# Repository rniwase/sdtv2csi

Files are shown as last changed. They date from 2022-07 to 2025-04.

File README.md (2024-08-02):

# sdtv2csi - SDTV to MIPI CSI-2 Video Decoder
Board for converting SDTV analog video to MIPI CSI-2 using Analog Devices ADV7280A-M.

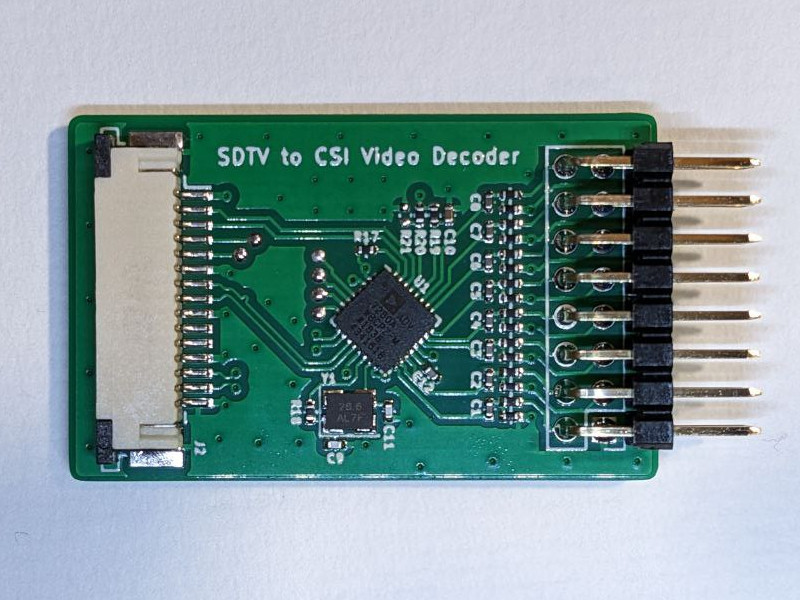
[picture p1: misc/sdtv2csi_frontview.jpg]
sdtv2csi topview

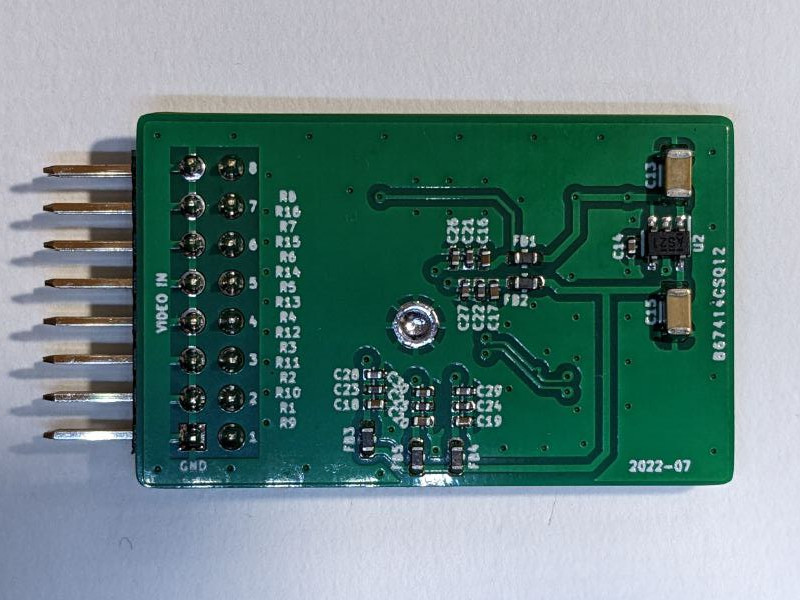
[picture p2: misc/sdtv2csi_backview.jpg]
sdtv2csi backview


## Configuration example in Raspberry Pi 4
1. Get and run kernel patch installation scripts
```
wget https://github.com/rniwase/sdtv2csi/raw/master/rpi/install_patch.sh
sudo bash install_patch.sh
```

2. Set dtoverlay in config.txt
```
# for Raspberry Pi OS Bookworm:
sudo bash -c 'echo "dtoverlay=adv728x-m,adv7280m=1" >> /boot/firmware/config.txt'
# for Raspberry Pi OS Bullseye:
sudo bash -c 'echo "dtoverlay=adv728x-m,adv7280m=1" >> /boot/config.txt'
```

3. Reboot the system and check for devices.
```
sudo reboot
sudo v4l2-ctl --all -d /dev/video0
```

### Operation check by FFmpeg
1. Connect NTSC composite video signal to VIDEO_IN pin header AIN1-GND

2. Install FFmpeg
```
sudo apt update
sudo apt install ffmpeg
```

3. Video recording
```
# Record full video including blanking line
ffmpeg -an -video_size 720x507 -r 29.97 -i /dev/video0 -c:v rawvideo -vf realtime -t 5 out.asf
# Record video with blanking lines cropped
ffmpeg -an -video_size 720x507 -r 29.97 -i /dev/video0 -c:v rawvideo -vf realtime,crop=720:480:0:27 -t 5 out_crop.asf
```

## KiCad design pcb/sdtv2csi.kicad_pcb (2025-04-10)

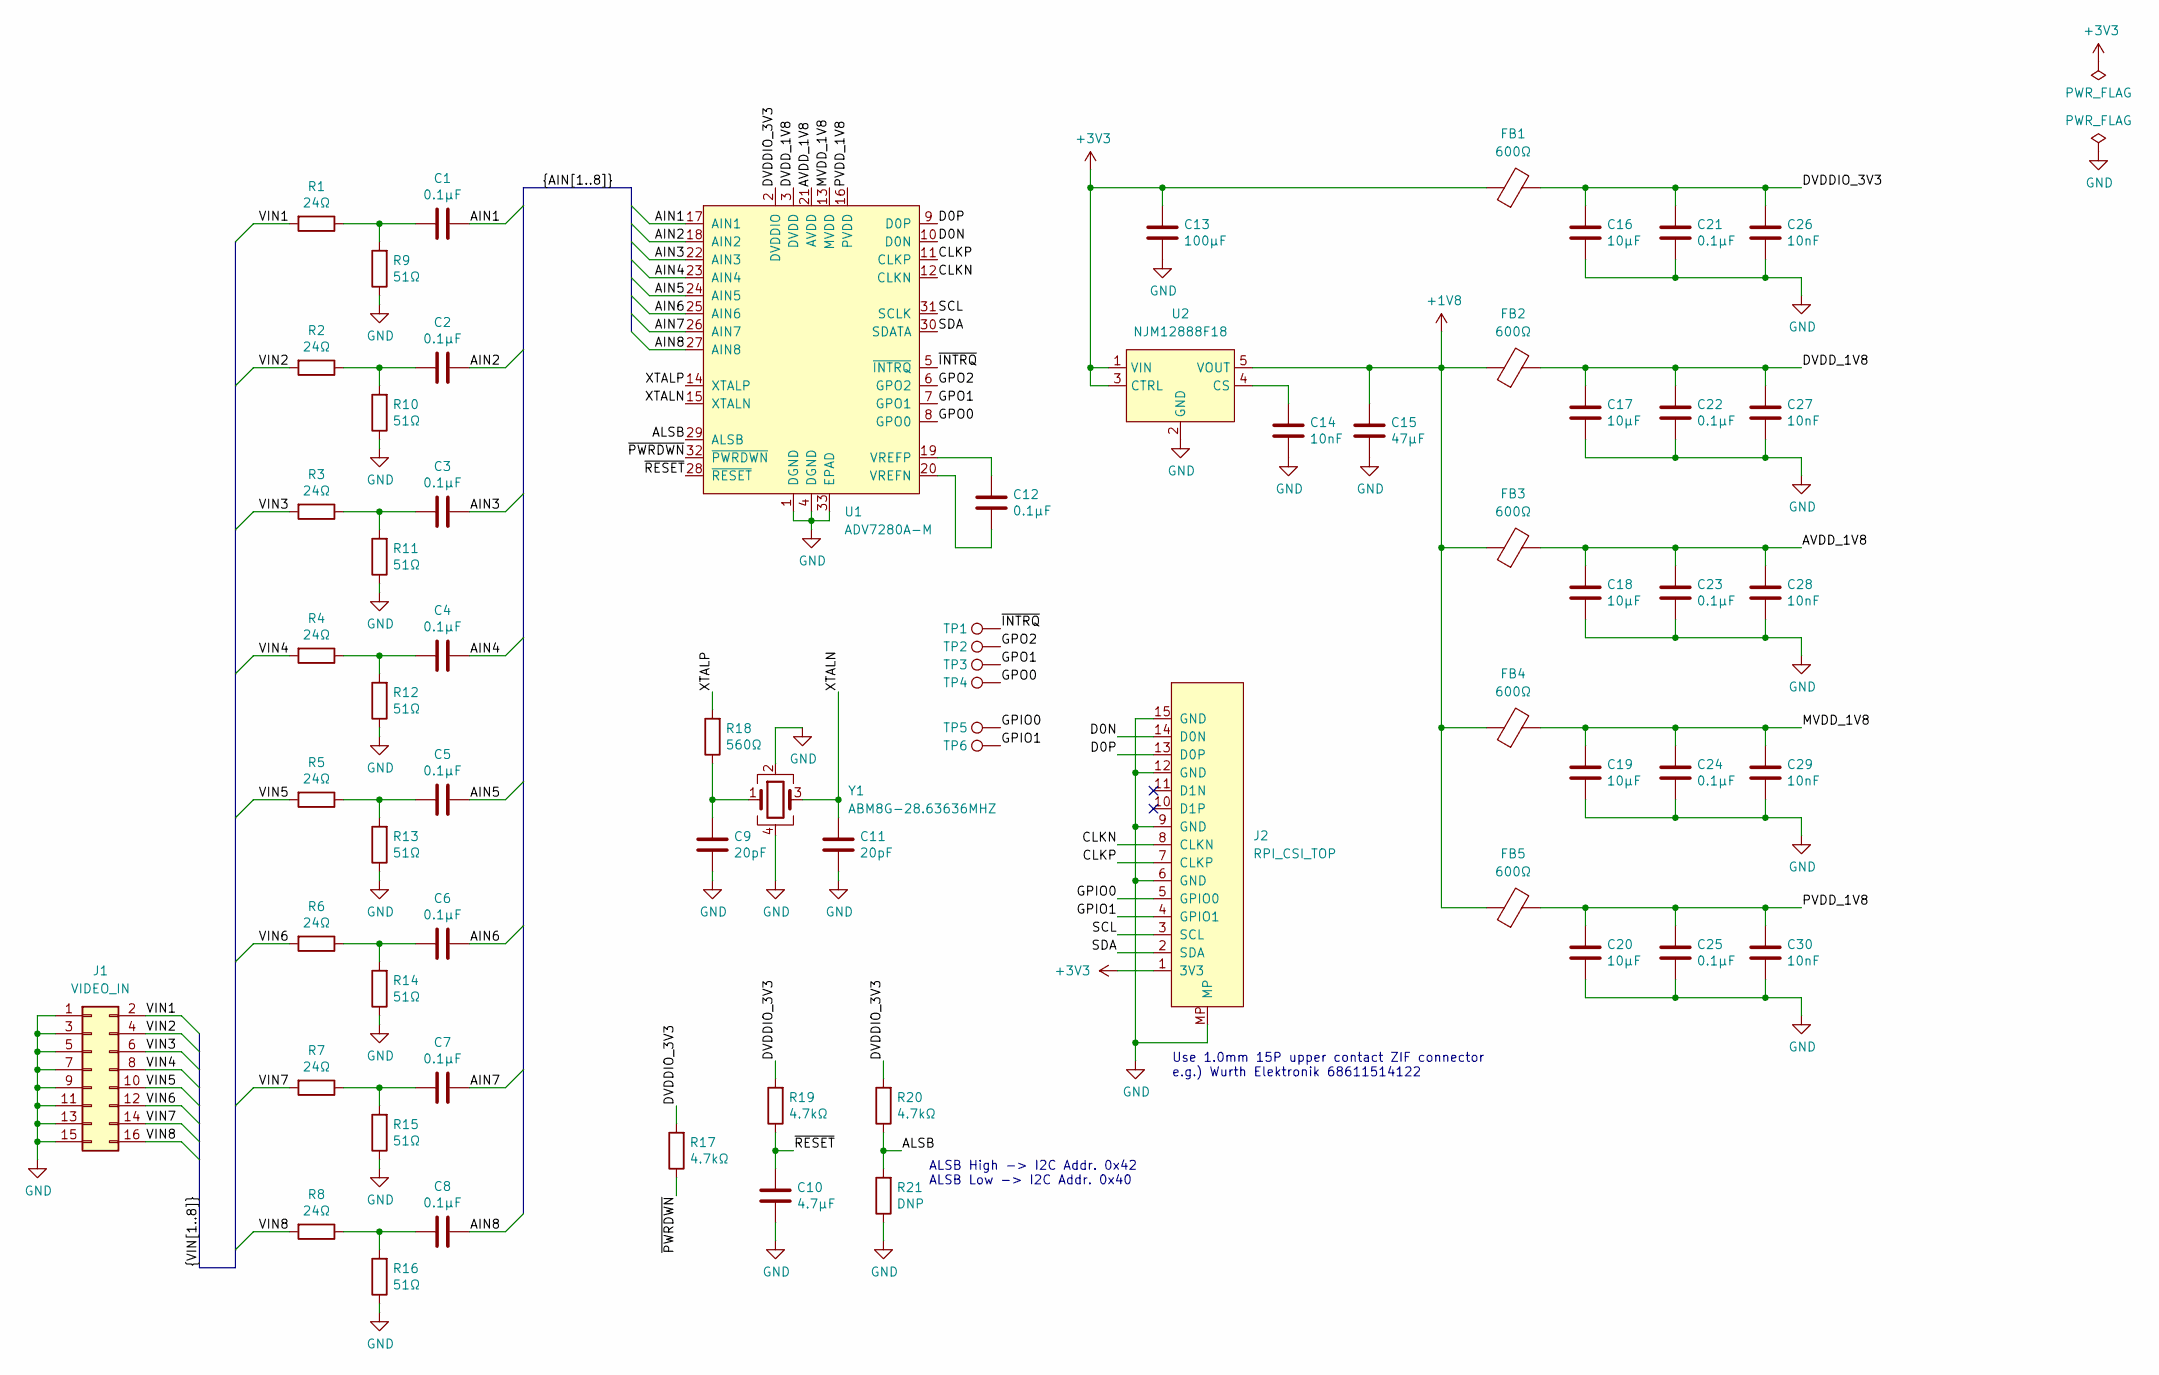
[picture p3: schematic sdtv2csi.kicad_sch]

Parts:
C1, C2, C3, C4, C5, C6, C7, C8, C12, C21, C22, C23, C24, C25: 0.1μF; C_0402_1005Metric
C9, C11: 20pF; C_0402_1005Metric
C10: 4.7μF; C_0402_1005Metric
C13: 100μF; C_1206_3216Metric
C14, C26, C27, C28, C29, C30: 10nF; C_0402_1005Metric
C15: 47μF; C_1206_3216Metric
C16, C17, C18, C19, C20: 10μF; C_0402_1005Metric
FB1, FB2, FB3, FB4, FB5: 600Ω; L_0603_1608Metric
J1: VIDEO_IN; PinHeader_2x08_P2.54mm_Vertical
J2: RPI_CSI_TOP; TE_1-84953-5_1x15-1MP_P1.0mm_Horizontal
R1, R2, R3, R4, R5, R6, R7, R8: 24Ω; R_0402_1005Metric
R9, R10, R11, R12, R13, R14, R15, R16: 51Ω; R_0402_1005Metric
R17, R19, R20: 4.7kΩ; R_0402_1005Metric
R18: 560Ω; R_0402_1005Metric
R21: DNP; R_0402_1005Metric
TP1, TP2, TP3, TP4, TP5, TP6: TestPoint; TestPoint_Pad_D1.0mm
U1: ADV7280A-M; LFCSP-32-1EP_5x5mm_P0.5mm_EP3.25x3.25mm
U2: NJM12888F18; SOT-23-5
Y1: ABM8G-28.63636MHZ; Crystal_SMD_3225-4Pin_3.2x2.5mm

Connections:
+1V8: C15.1, FB2.1, FB3.1, FB4.1, FB5.1, U2.5 (VOUT)
+3V3: C13.1, FB1.1, J2.1 (3V3), U2.1 (VIN), U2.3 (CTRL)
/AIN1: C1.1, U1.17 (AIN1)
/AIN2: C2.1, U1.18 (AIN2)
/AIN3: C3.1, U1.22 (AIN3)
/AIN4: C4.1, U1.23 (AIN4)
/AIN5: C5.1, U1.24 (AIN5)
/AIN6: C6.1, U1.25 (AIN6)
/AIN7: C7.1, U1.26 (AIN7)
/AIN8: C8.1, U1.27 (AIN8)
/ALSB: R20.1, R21.2, U1.29 (ALSB)
/AVDD_1V8: C18.1, C23.1, C28.1, FB3.2, U1.21 (AVDD)
/CLKN: J2.8 (CLKN), U1.12 (CLKN)
/CLKP: J2.7 (CLKP), U1.11 (CLKP)
/D0N: J2.14 (D0N), U1.10 (D0N)
/D0P: J2.13 (D0P), U1.9 (D0P)
/DVDDIO_3V3: C16.1, C21.1, C26.1, FB1.2, R17.2, R19.2, R20.2, U1.2 (DVDDIO)
/DVDD_1V8: C17.1, C22.1, C27.1, FB2.2, U1.3 (DVDD)
/GPIO0: J2.5 (GPIO0), TP5.1
/GPIO1: J2.4 (GPIO1), TP6.1
/GPO0: TP4.1, U1.8 (GPO0)
/GPO1: TP3.1, U1.7 (GPO1)
/GPO2: TP2.1, U1.6 (GPO2)
/MVDD_1V8: C19.1, C24.1, C29.1, FB4.2, U1.13 (MVDD)
/PVDD_1V8: C20.1, C25.1, C30.1, FB5.2, U1.16 (PVDD)
/SCL: J2.3 (SCL), U1.31 (SCLK)
/SDA: J2.2 (SDA), U1.30 (SDATA)
/VIN1: J1.2, R1.2
/VIN2: J1.4, R2.2
/VIN3: J1.6, R3.2
/VIN4: J1.8, R4.2
/VIN5: J1.10, R5.2
/VIN6: J1.12, R6.2
/VIN7: J1.14, R7.2
/VIN8: J1.16, R8.2
/XTALN: C11.1, U1.15 (XTALN), Y1.3
/XTALP: R18.2, U1.14 (XTALP)
/~INTRQ: TP1.1, U1.5 (~INTRQ)
/~PWRDWN: R17.1, U1.32 (~PWRDWN)
/~RESET: C10.1, R19.1, U1.28 (~RESET)
GND: C9.2, C10.2, C11.2, C13.2, C14.2, C15.2, C16.2, C17.2, C18.2, C19.2, C20.2, C21.2, C22.2, C23.2, C24.2, C25.2, C26.2, C27.2, C28.2, C29.2, C30.2, J1.1, J1.3, J1.5, J1.7, J1.9, J1.11, J1.13, J1.15, J2.6 (GND), J2.9 (GND), J2.12 (GND), J2.15 (GND), J2.MP, R9.1, R10.1, R11.1, R12.1, R13.1, R14.1, R15.1, R16.1, R21.1, U1.1 (DGND), U1.4 (DGND), U1.33 (EPAD), U2.2 (GND), Y1.2, Y1.4
unnamed: C1.2, R1.1, R9.2
unnamed: C2.2, R2.1, R10.2
unnamed: C3.2, R3.1, R11.2
unnamed: C4.2, R4.1, R12.2
unnamed: C5.2, R5.1, R13.2
unnamed: C6.2, R6.1, R14.2
unnamed: C7.2, R7.1, R15.2
unnamed: C8.2, R8.1, R16.2
unnamed: C9.1, R18.1, Y1.1
unnamed: C12.2, U1.20 (VREFN)
unnamed: C12.1, U1.19 (VREFP)
unnamed: C14.1, U2.4 (CS)

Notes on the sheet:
Use 1.0mm 15P upper contact ZIF connector e.g.) Wurth Elektronik 68611514122
ALSB High -> I2C Addr. 0x42 ALSB Low -> I2C Addr. 0x40

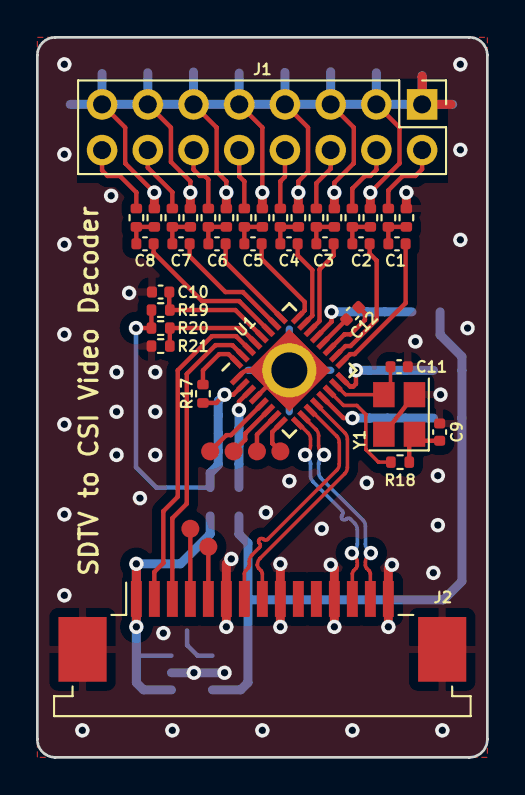
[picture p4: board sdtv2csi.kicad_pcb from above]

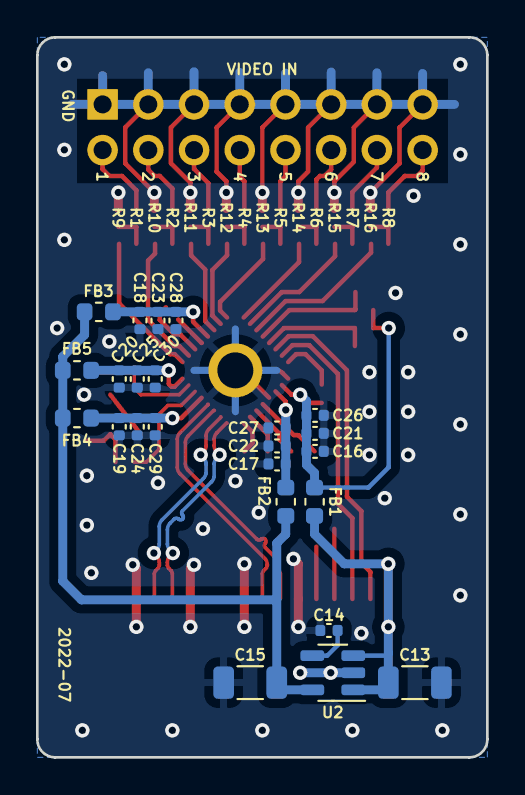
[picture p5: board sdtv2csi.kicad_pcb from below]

Board: 2 copper layers, 25.0 x 40.0 mm, 67 parts (24 on the bottom side), 53 nets.

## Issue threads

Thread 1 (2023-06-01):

image sync problem?

lerabot, 2023-06-01:
Hello, first of all thank you for your pcb layout :) I fab'd 5 board last month and they work great.

I have an image sync issue and I'm wonderig you you had the same problem, check the screenshot.

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

I'm capturing using s-video NTSC, but I can see this problem even on composite.

rniwase, 2023-06-03:
Hi, @lerabot. Thanks for making sure it works.

I am aware of this problem and apologize for not announcing it in advance.

I have tried to solve this problem by directly rewriting the registers of the ADV7280A-M, but I have not been able to solve it yet.

I believe that the problem is probably in the hardware design.
In particular, there may be a fault in the power supply or the MIPI CSI transmission line.

I am too busy with other work to tackle this problem right now,
but I will try to get an evaluation board from Analog Devices someday to compare the operation.

lerabot, 2023-06-03:
Thank for the quick feedback. I might try to write a script that try to detect and stitch the image together for the time being.

Also, I posted on the raspberry pi forum about this. https://forums.raspberrypi.com/viewtopic.php?p=2111105#p2110939

I might try to hack together something with the ADM7280 driver at some point to try to correct the power up timing sequence.

lerabot, 2024-07-02:
Hello again. I'm resuming work on this and will try hacking with the register again. If you have any clues on how to fix this in software, I'll gladly take them.

rniwase, 2024-07-29:
Thanks for waiting so long.
I'd like to share what I've learned in the past few weeks.

As answered in the Raspberry Pi or Analog Devices forums, the data output by the ADV7280-M with NTSC as input format, ITU-R BT.656-3 as output format, and I2P enabled is not 480 lines per frame, but The data output by ADV7280-M is not 480 lines per frame, but 507 lines per frame including blanking data.

For this, I actually confirmed using an FPGA board (TE0726-03M) and MIPI CSI-2 receiver that 507 YUV422 packets come per frame.
The relationship between video format settings and output resolution is described in detail in Table 72 of the device manual (UG-1176).
https://www.analog.com/media/en/technical-documentation/user-guides/ADV7280A-7281A-7282A-UG-1176.pdf

However, the device driver in Linux kernel 6.1.y running on Raspberry Pi OS Bullseye is set at a height to reserve a buffer of 480 lines per frame, so the 27 lines of difference are overwritten at the top of the buffer when recording It seems that 27 lines of the difference are overwritten at the top of the buffer when recording.
The result is a problem that results in images that appear to be out of sync.

To solve the problem, I changed the height in the device driver (adv7180.c) to 507 instead of 480.

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

This allows the user to obtain a complete image, although the upper 27 lines contain extra blanking data.

I feel that to solve all of these problems, not only the ADV7280 device driver, but also unicam and V4L2 API must be investigated thoroughly.

(Dear @6by9, author of the great adv7180 driver. If you have any advice on this area, we would appreciate your comments...)

My environment and kernel module build procedure are shown below.

- Board: Raspberry Pi 4B 8GB
- OS: Raspberry Pi OS Lite 64-bit (Bullseye)
```
$ uname -a
Linux svr-tommib 6.1.21-v8+ #1642 SMP PREEMPT Mon Apr  3 17:24:16 BST 2023 aarch64 GNU/Linux
$ cat /etc/os-release
PRETTY_NAME="Debian GNU/Linux 11 (bullseye)"
NAME="Debian GNU/Linux"
VERSION_ID="11"
VERSION="11 (bullseye)"
VERSION_CODENAME=bullseye
ID=debian
HOME_URL="https://www.debian.org/"
SUPPORT_URL="https://www.debian.org/support"
BUG_REPORT_URL="https://bugs.debian.org/"
```
```
# Enter root login shell
sudo su -

# Install dependencies
apt-get update
apt-get -y upgrade
apt-get -y install git bc bison flex libssl-dev

# Download the corresponding Linux kernel source from the Git hash of the specific firmware
# Note: The following is for kernel version 6.1.21-v8+
FW_GIT=1440b3e0b52075a9ec244216cddcf56099c28dfa
KERNEL_GIT=$(curl -fL https://github.com/raspberrypi/rpi-firmware/raw/${FW_GIT}/git_hash)
curl -fL https://github.com/raspberrypi/linux/archive/${KERNEL_GIT}.tar.gz | tar -zx -C /usr/src/

# Download symbol file
curl -fL https://github.com/raspberrypi/rpi-firmware/raw/${FW_GIT}/Module8.symvers > /usr/src/linux-${KERNEL_GIT}/Module.symvers

# Porting configs from current system
modprobe configs
zcat /proc/config.gz > /usr/src/linux-${KERNEL_GIT}/.config

# Generate files needed to build kernel modules
cd /usr/src/linux-${KERNEL_GIT}/
make -j$(nproc) modules_prepare

# Preparing for adv7180 kernel module build
mkdir /root/adv7180_hack/
cd /root/adv7180_hack/
cp /usr/src/linux-${KERNEL_GIT}/drivers/media/i2c/adv7180.c ./
echo "obj-m := adv7180.o" > Makefile

# Modify adv7180.c
sed -i.bak -e "s/480 : 576/507 : 576/" adv7180.c
diff adv7180.c.bak adv7180.c
742c742
<       fmt->height = state->curr_norm & V4L2_STD_525_60 ? 507 : 576;
---
>       fmt->height = state->curr_norm & V4L2_STD_525_60 ? 480 : 576;

# Build modified adv7180 kernel module
make -C /usr/src/linux-${KERNEL_GIT}/ M=$PWD

# Install modified module
mv /lib/modules/$(uname -r)/kernel/drivers/media/i2c/adv7180.ko.xz /lib/modules/$(uname -r)/kernel/drivers/media/i2c/adv7180.ko.xz.bak
xz -c /root/adv7180_hack/adv7180.ko > /lib/modules/$(uname -r)/kernel/drivers/media/i2c/adv7180.ko.xz

# Setup dtoverlay and reboot
echo "dtoverlay=adv728x-m,adv7280m=1" >> /boot/config.txt
reboot
```
```
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
rniwase, 2024-08-02:
@lerabot I have updated the procedure in the README of this commit ([694bd97](https://github.com/rniwase/sdtv2csi/commit/694bd97d56bf460c1c3092f00c0b61747ea7d74c)).

I initially expected that there was something wrong with the hardware (PCB) design, but it turns out that I can work around this problem by rewriting the device driver.

so please refer to the procedure and check the operation.

lerabot, 2024-08-08:
Hello to both of you and thank for all your research.
In the past month or so I've followed and read a bunch of those topic and applied a very similar patch myself.

I'll test your version of the patch tomorrow or today and see if I can get better result.

6by9, 2024-08-12:
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

Whilst I did have a branch that allowed reception of interlaced content (ie I2P disabled), it was a bit too hacky to be merged as the Unicam driver needed knowledge of how the ADV signaled the field (using the frame count value IIRC).

I'll see if I can find a few minutes to hack together testing with BT656-4 register tweaked, and whether it makes a useful difference.

Producing 507 lines feels wrong - it'd be nice to investigate further, but I doubt I'll have time. ADI may answer further on their forums if the question is asked.

Seeing as I have a couple of patches for this chip that would be worth sending upstream, I may send the trivial fix above along with it to at least start the discussion. I don't know how the crop should be advertised though, and want to confirm 507 vs 525 lines as well.

lerabot, 2024-08-21:
Been working on this for the past couple of days. It's a shame that we can't get proper interlaced capture because I'm fairly sure we could get a better quality out of software deinterlacer. I've been looking at the interlaced unicam driver and it does seem quite hacky. I'll try to give a try later.

6by9, 2024-08-21:
The issue is that there is no standardisation as to how things like interlacing should be signaled on CSI2, and V4L2's frameworks don't provide a mechanism for the receiver to pass side-band information back to the source device driver to give it a chance to interpret it and amend buffer descriptors accordingly.

Looking at my branch at https://github.com/6by9/linux/tree/rpi-5.10.y-unicam-interlaced, ADV728x uses the 16bit frame_count field in the frame start and end packets.

The Toshiba TC358743 HDMI to CSI2 bridge can also receive interlaced content, however it sends the 2 fields with different CSI2 data types. It would therefore need a similar routine to set the interlacing flags, but based on UNICAM_CDT instead of UNICAM_CWC. (We'd also need to programme both DTs that represent the interlaced image data).

IIRC The I2P block is a relatively simple line doubler, or possibly interpolate between the 2 lines in each field. Yes software could probably do a more comprehensive job.
Please be aware that the VideoCore VPU deinterlacer doesn't handle YUYV data (only planar YUV420), so you would have to be running it on the ARM cores. As the buffers that are used by the CSI2 receiver are uncached, you may have a performance penalty there.

lerabot, 2024-09-06:
@rniwase I'm currently making a variant of your circuit as a raspberry pi zero hat. You mentioned making some mistake with the circuit, do you care to elaborate more, I could integrate those changes in this new version. I will post the source here https://github.com/lerabot/dvx-nebula

rniwase, 2024-09-07:
@lerabot at this time, I don't believe that there is any problem with the circuit design.
I know that the out-of-sync symptom is a compatibility issue between the RPi camera input and the device driver, and is not caused by the circuit design.

And I am honored that my work will be incorporated into your project. I hope it will work.

lerabot, 2024-11-01:
Hello rniwase. I just received the ADV7280 Hat for the Pi Zero. If you'd like one I'll ship you one for free.
Just email me your address at ( r.rabot at gmail dot com)

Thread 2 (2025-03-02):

Replacement of NJM12888F18

l0l0l0, 2025-03-02:
Hello,

I'm having trouble finding the NJM12888F18 in SOT-25 as a single unit, so I'm looking for a replacement. Do you have any recommendations? It seems that the Texas Instruments TLV70218 could be a suitable alternative.

I also found some NJM12888F18 in stock, but in the DFN6-G1 package. I could modify the PCB to accommodate it, but I'm concerned about introducing noise. Do you have any recommendations regarding this?

Thank you!

rniwase, 2025-03-03:
Hi, @l0l0l0.

> I'm having trouble finding the NJM12888F18 in SOT-25 as a single unit, so I'm looking for a replacement. Do you have any recommendations? It seems that the Texas Instruments TLV70218 could be a suitable alternative.

I can't immediately give specific examples because I have not considered any alternatives, but I believe it is possible to replace the TLV70218 without making any changes to the design. If you adopt it, the 10nF capacitor in C14 is not necessary, but it would be best to change the design to connect the NC pin of the LDO to GND for heat dissipation.

> I also found some NJM12888F18 in stock, but in the DFN6-G1 package. I could modify the PCB to accommodate it, but I'm concerned about introducing noise. Do you have any recommendations regarding this?

I don't see any description in the datasheet that the output noise voltage varies depending on the package, so I think there should be nothing wrong with changing the package. If you want to replace the footprint with DFN6-G1, make the area of the GND plane as large as possible and modify the design so that the exposed pad is connected there.

In any case, it is advisable to check for abnormal heat generation during operation and that the output voltage of the LDO is not oscillating.

l0l0l0, 2025-03-03:
Hello @rniwase,

Thank you so much for all this information. I will use the TV70218 and modify the PCB as you advised. Thanks again and congratulations on your project!

Closed 2025-03-03.

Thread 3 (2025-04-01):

Issue generating gerber

ansib1e, 2025-04-01:
hoping to get in touch to get some help with generating a gerber/pcb based on your design. Am new to this and am eager to learn if you have the time!

rniwase, 2025-04-10:
I migrated to the latest KiCad 9.0.1 because the project version was a bit old.
Please read the KiCad documentation on how to create Gerber files.

However, I have just made Gerber files, schematics, etc. available for download from the release page.
[https://github.com/rniwase/sdtv2csi/releases](https://github.com/rniwase/sdtv2csi/releases)

Please refer to the contents of sdtv2csi-board.pdf for PCB manufacturing rules.

Closed 2025-04-16.

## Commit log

2022-07-05 migrate to KiCAD 6.0, update schematic wip
    [csi-analogvideo-capture.kicad_pcb, csi-analogvideo-capture.kicad_sch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]
2022-07-07 update schematicand pcb, DRC passed
    [csi-analogvideo-capture.kicad_pcb, csi-analogvideo-capture.kicad_sch]
2022-07-07 place silkscreen
    [csi-analogvideo-capture.kicad_pcb]
2022-07-09 update pcb
    [csi-analogvideo-capture.kicad_pcb]
2022-07-09 clean up project, update pcb
    [csi-analogvideo-capture.kicad_pcb, csi-analogvideo-capture.kicad_sch]
2022-07-09 rename project
    [csi-analogvideo-capture.sch, sdtv2csi.kicad_pcb, sdtv2csi.kicad_sch]
2022-10-12 add boardviews
2025-04-10 pcb: migrate KiCad to 9.0.1
    [sdtv2csi.kicad_pcb, sdtv2csi.kicad_sch]
